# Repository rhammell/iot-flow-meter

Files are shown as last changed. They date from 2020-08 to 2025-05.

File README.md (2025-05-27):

# iot-flow-meter
This repository contains the project files used to build an IoT enabled flow meter. This project was submitted to Hackster.io as part of the [Cellular IoT Challenge](https://www.hackster.io/contests/soracomcontest#category-331), where it was selected as the grand prize winner. 

Read the [project page](https://www.hackster.io/rhammell/river-monitoring-with-an-iot-flow-meter-9af852) on Hackster.io for a complete project description and build tutorial. 

# Overview

<p align="center">
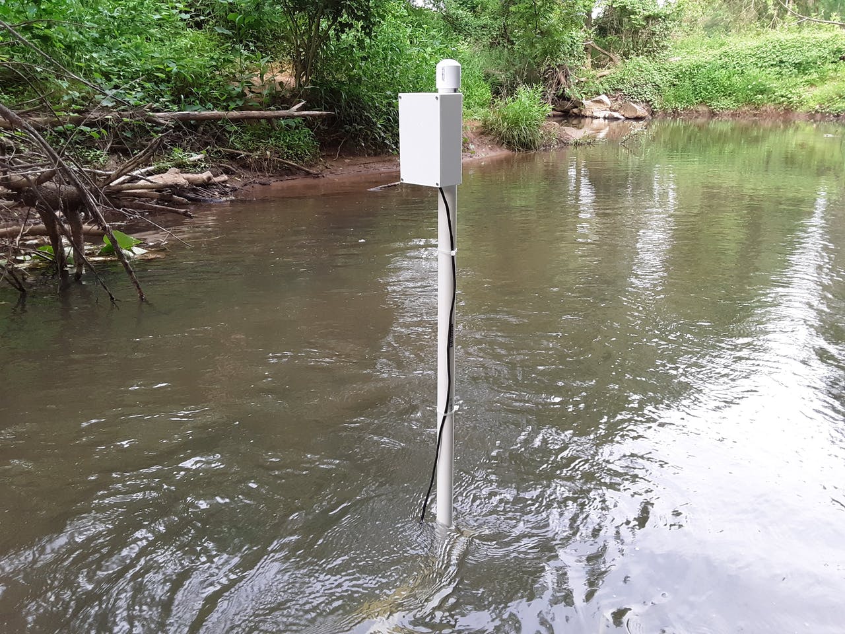
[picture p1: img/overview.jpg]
  
  <br>
  <span><i>IoT flow meter deployed to a local river</i></span>
</p>

This project demonstrates how to build an internet connected flow meter that continuously measures a river's flow rate and makes real-time data available to users online.

The system can be deployed to remote rivers with a one-time setup, and can be left to run on its own, automatically collecting data without the need for users to be present. Multiple meters can be placed throughout a river to collect many points of data.

Measurement data is pushed to the cloud through the system's cellular network connectivity, enabled by a Soracom Global SIM card, and can be viewed online through Soracom Harvest. AWS IoT and CloudWatch services are used to send email notifications to users when the river's flow rate reaches a critical level.

# Background

<p align="center">
  
</p>

The flow rate of a river measures the volume of water that passes through a specific point over time. This rate rises and falls as water from rainfall flows in and out of the river system.

Measuring a river's flow rate can yield valuable information for a variety purposes:

- Hydrology: Long term trends in flow rate give insights into the watershed system that feeds the river and how it changes over time.
- Ecology: Speed of river water determines if it can support different species of plants or animals.
- Flood Warning: Spikes in the flow rate can give early warning for incoming flooding and can be correlated to rainfall reports.
- Recreation Safety: Real-time measurements can warn canoers/kayakers if it is safe to travel along the river.

Currently, measuring the flow rate of remote river areas is a very hands-on process. Surveyors need to hike out to the river of interest carrying their measuring equipment, set it up, take a measurement, disassemble it, and hike back.

Because of the effort required to collect a measurement, it is only done periodically for certain rivers. Without continuous monitoring many of the insights that flow rate provides are lost.

This project aims to solve this problem by making flow rate data easier to collect and more readily available to users who need it.

# How it Works

<p align="center">
  <a target="_blank" href="https://www.youtube.com/watch?v=L7kpcUOq6Nk">
    
  </a>
  <br>
  <span><i>IoT Flow Meter Overview Video</i></span>
</p>

The IoT flow meter consists of a sensor and electronics, connected to a PVC pipe support structure, that can be deployed to a river to collect flow rate data.

A flow meter sensor is connected to the structure's vertical pipe at an adjustable height where it is held submerged underwater. The electronics are contained in an upper housing at the top of the structure outside of the water.

<p align="center">
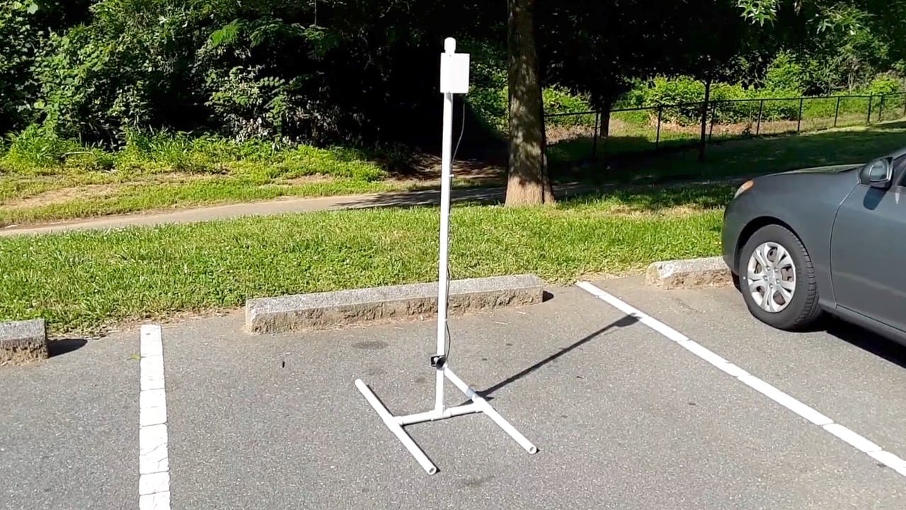
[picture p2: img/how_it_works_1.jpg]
  
  <br>
  <span><i>IoT flow meter structure and components</i></span>
</p>
<p align="center">
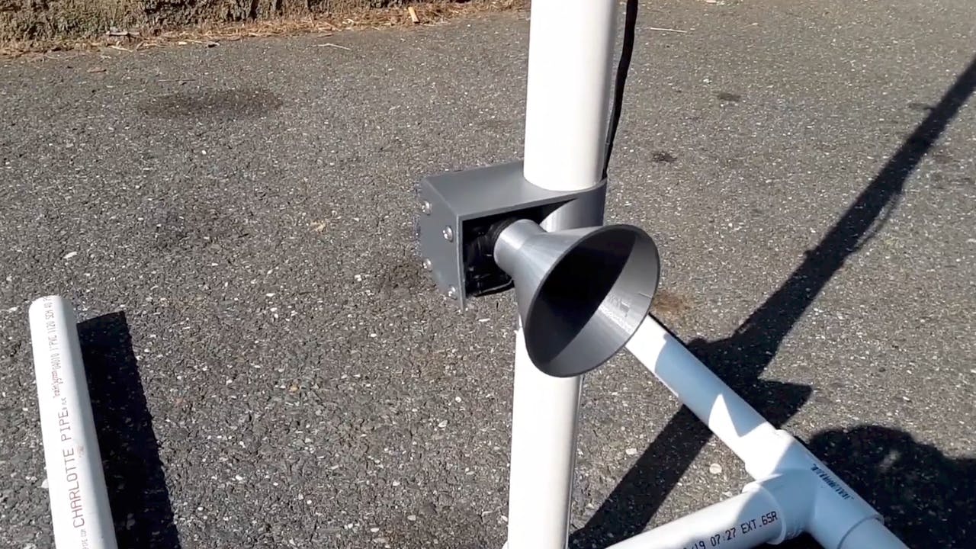
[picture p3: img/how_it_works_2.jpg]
  
  <br>
  <span><i>Flow meter sensor connected to structure</i></span>
</p>
<p align="center">
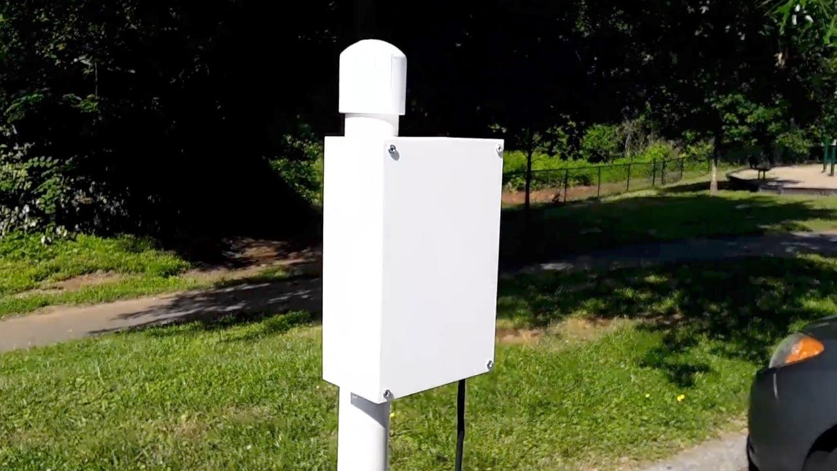
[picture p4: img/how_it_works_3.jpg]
  
  <br>
  <span><i>IoT flow meter deployed to a local river</i></span>
</p>

The system utilizes a YF-S201 liquid flow meter sensor, which contains a magnetic pinwheel that is spun by incoming water.

As more water enters the sensor the wheel spins faster, and this rate of spin (Hz) can be used to calculate how many liters of water flow through the sensor per minute (L/min), called the flow rate.

<p align="center">
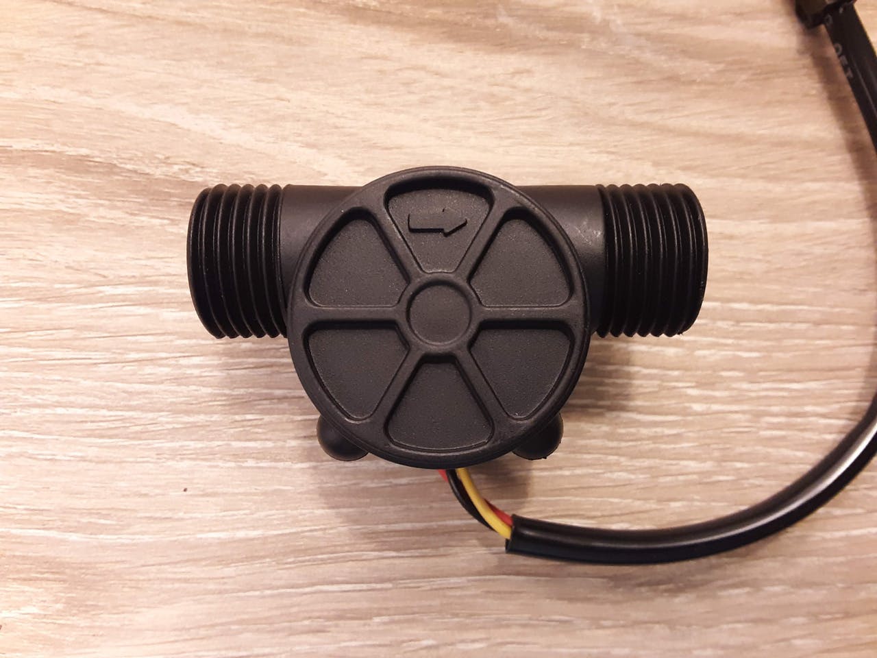
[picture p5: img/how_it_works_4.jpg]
  
  <br>
  <span><i>YF-S201 liquid flow meter sensor</i></span>
</p>
<p align="center">
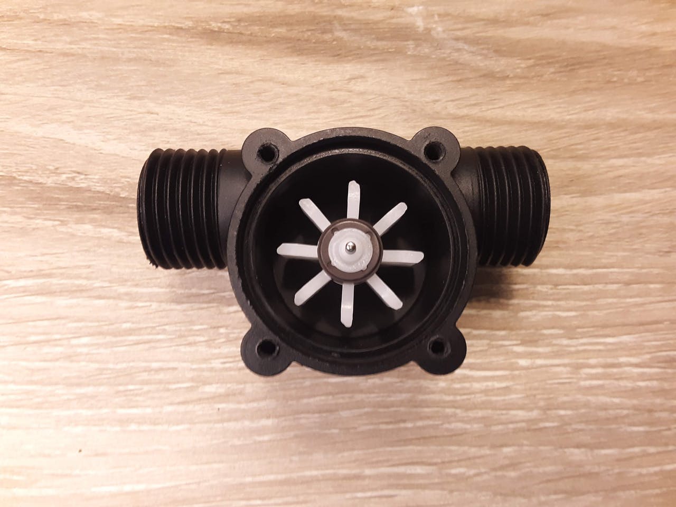
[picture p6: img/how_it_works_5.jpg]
  
  <br>
  <span><i>Magnetic pinwheel housed within the sensor</i></span>
</p>
<p align="center">
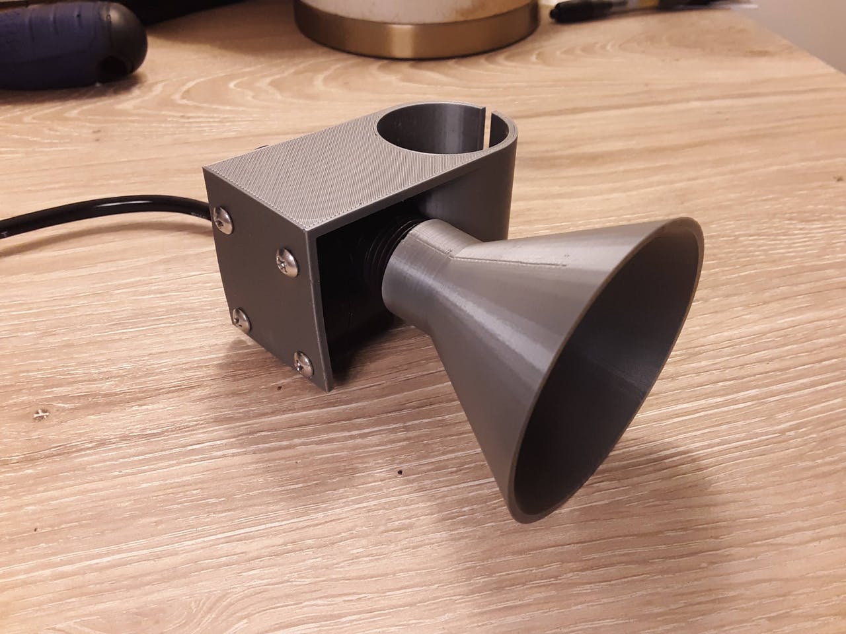
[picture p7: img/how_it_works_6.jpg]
  
  <br>
  <span><i>3D printed bracket and funnel attached to sensor</i></span>
</p>

Note: This flow rate only tells the liters of water passing through the sensor itself, not the entire river. The sensor's flow rate is strongly correlated to the river's actual flow rate, but is not measuring it directly. The IoT flow meter provides only the sensor's flow rate and uses this as an approximation for the entire river.

A 3D printed bracket is used to connect the sensor to the PVC pipe structure and a 3D printed funnel guides river water into the mouth of the sensor.

The electronics of the system include a Raspberry Pi, 3G USB modem with a Soracom Global SIM, and external battery, which are contained in a 3D printed housing. The sensor is connected to the Pi by water-sealed jumper wires that run the length of the vertical pipe into the housing.

<p align="center">
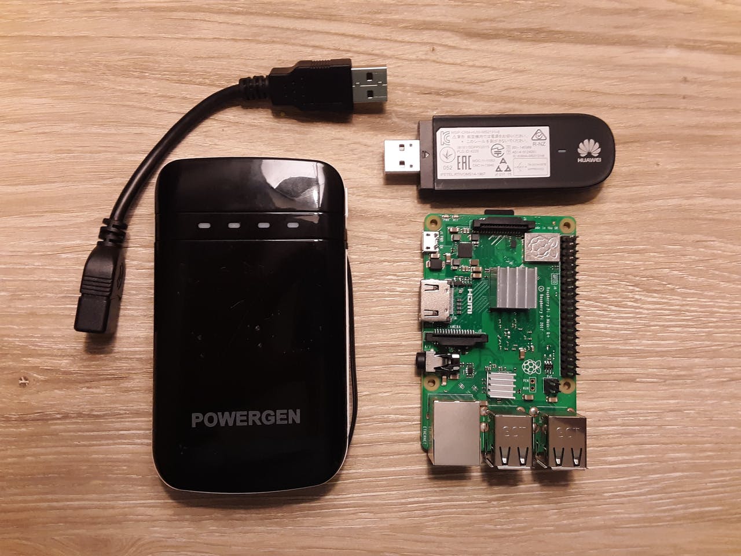
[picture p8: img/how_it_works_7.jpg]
  
  <br>
  <span><i>Raspberry Pi, 3G USB modem with Soracom Global SIM, and external battery</i></span>
</p>
<p align="center">
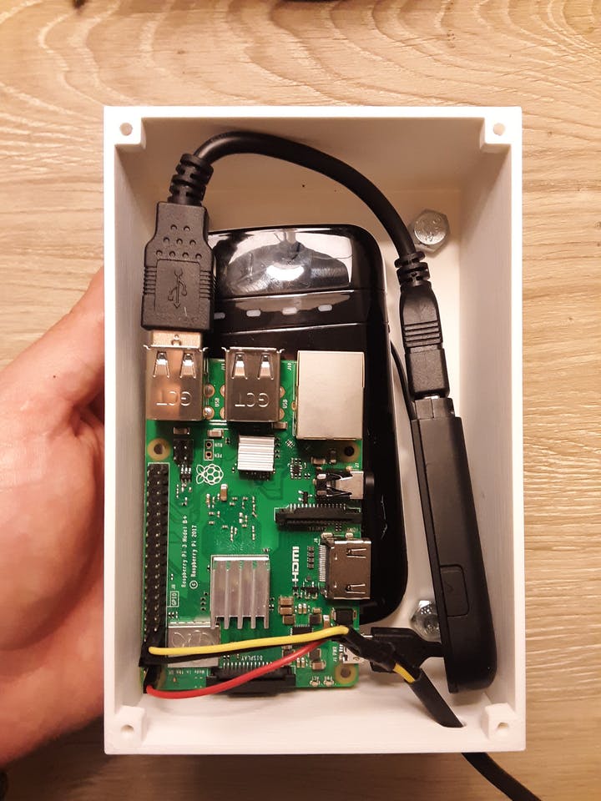
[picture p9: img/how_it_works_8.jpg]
  
  <br>
  <span><i>Electronics in 3D printed housing</i></span>
</p>

The Pi runs a Python script where ever minute a flow rate measurement is collected from the sensor and, using the cellular connectivity provided by the modem and SIM card, pushed to the cloud.

The script makes an HTTP POST request to Soracom's Unified Endpoint which forwards the data along to two services: Soracom Harvest and Soracom Funnel.

<p align="center">
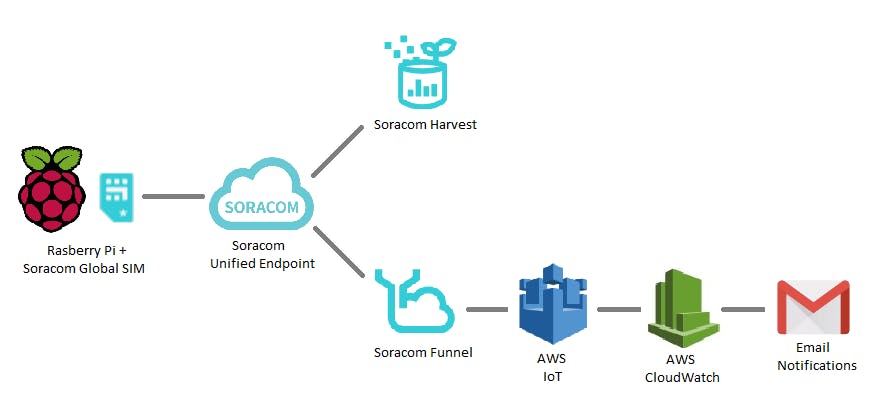
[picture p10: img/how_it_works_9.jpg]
  
  <br>
  <span><i>Overview of information flow</i></span>
</p>

Soracom Harvest allows for easy real-time visualization of the incoming data. The console displays a live graph showing updated data values as they stream in. Users can monitor how the data changes over a selected window of time.

<p align="center">
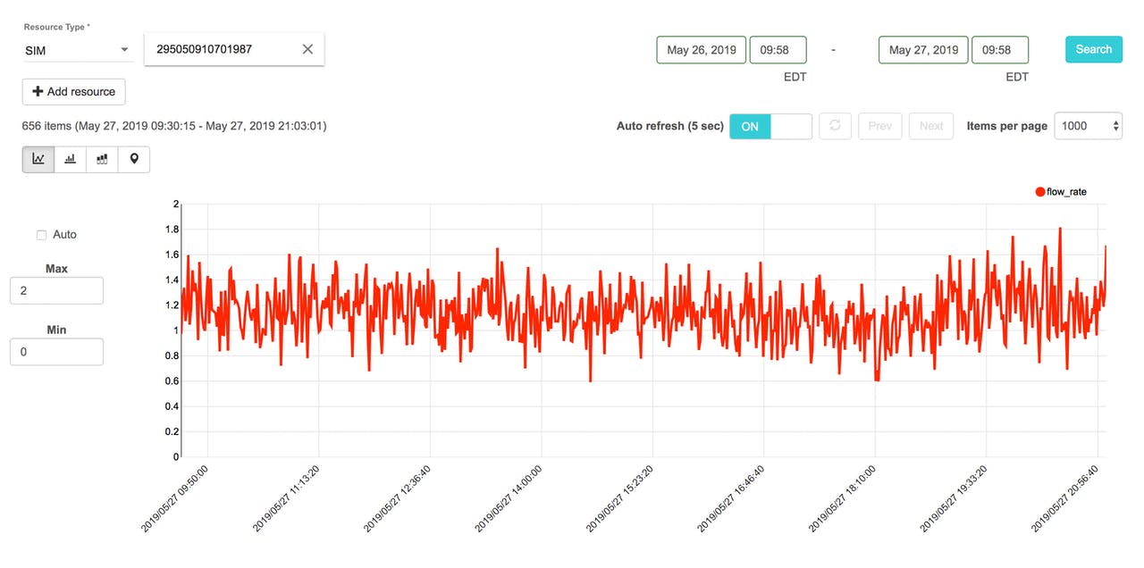
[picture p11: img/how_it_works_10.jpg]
  
  <br>
  <span><i>Soracom Harvest console</i></span>
</p>
<p align="center">
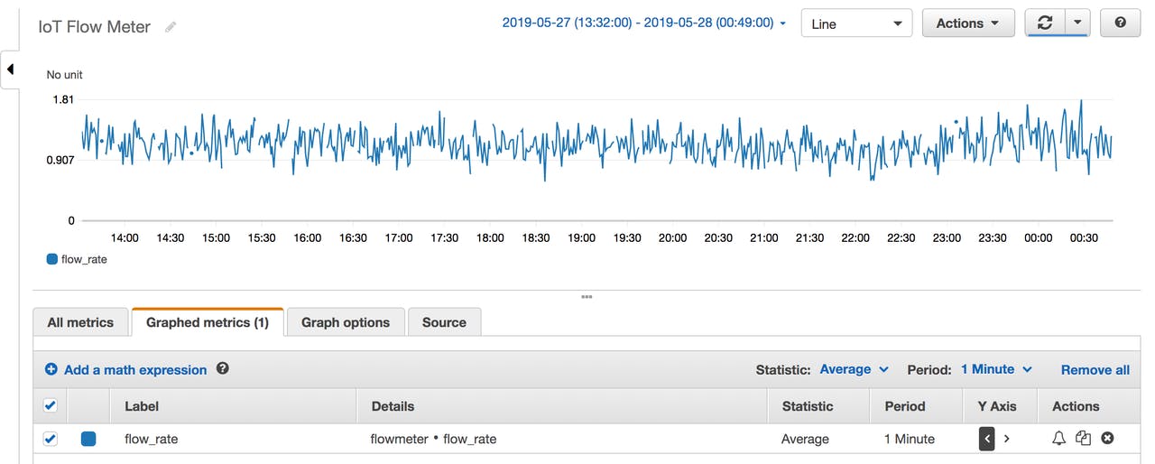
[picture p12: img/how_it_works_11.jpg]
  
  <br>
  <span><i>AWS Cloudwatch console</i></span>
</p>
<p align="center">
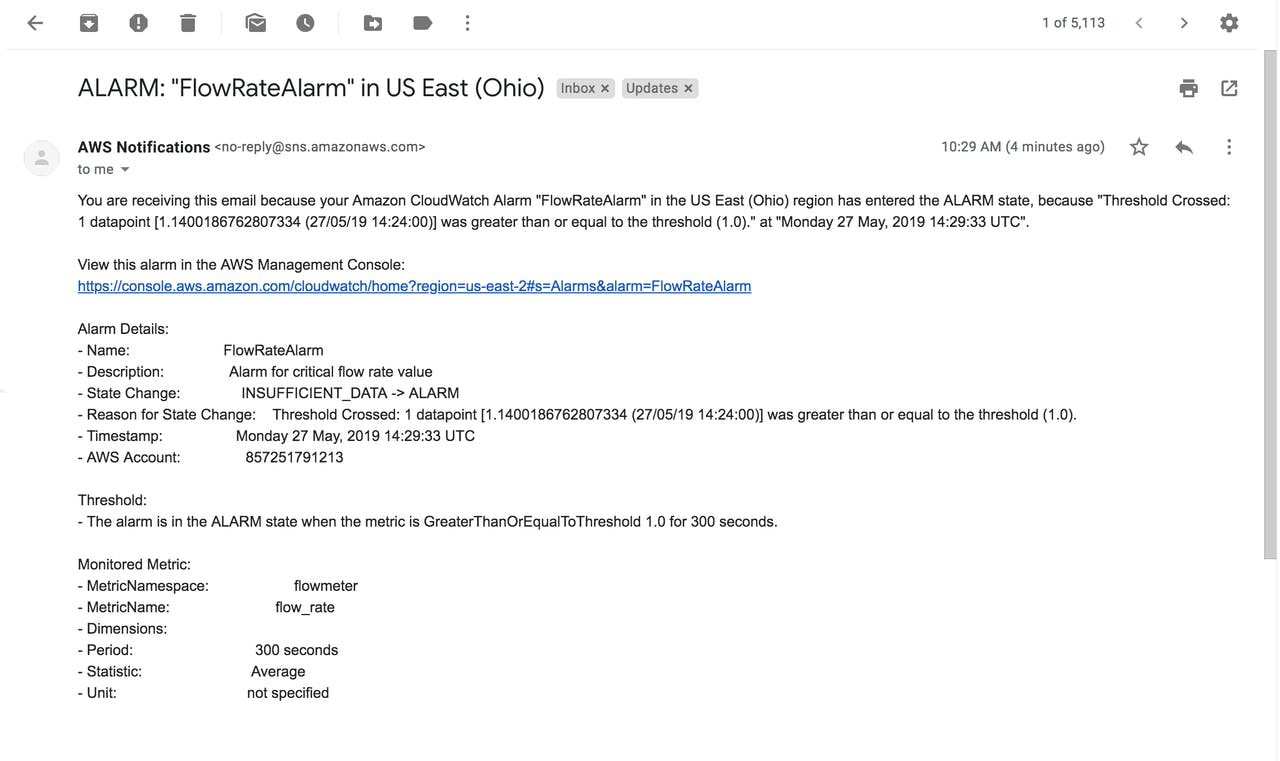
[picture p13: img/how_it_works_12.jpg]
  
  <br>
  <span><i>Email alarm notification</i></span>
</p>

Soracom Funnel takes the data and forwards it further on it by sending it to an AWS IoT endpoint, where an AWS IoT rule is then used to push the data to AWS CloudWatch.

A CloudWatch alarm is configured to monitor when the flow rate surpasses a critical value and automatically sends out an email notification to any subscribed users letting them know that the alarm has been triggered. This feature allows users to stay aware of important changes in the river's flow rate without having to monitor it live.

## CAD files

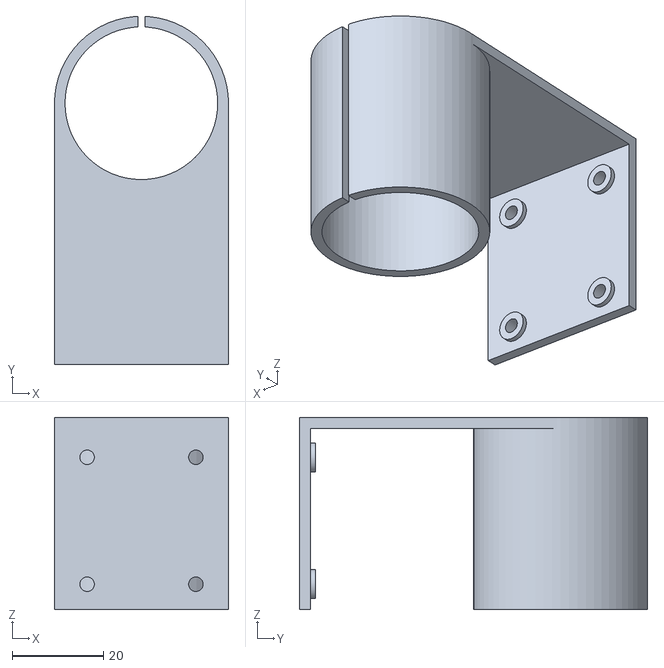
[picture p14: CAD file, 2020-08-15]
3d_models/flow_meter_bracket_oy0BGOlrMj.stl
38.1 x 76.2 x 42.1

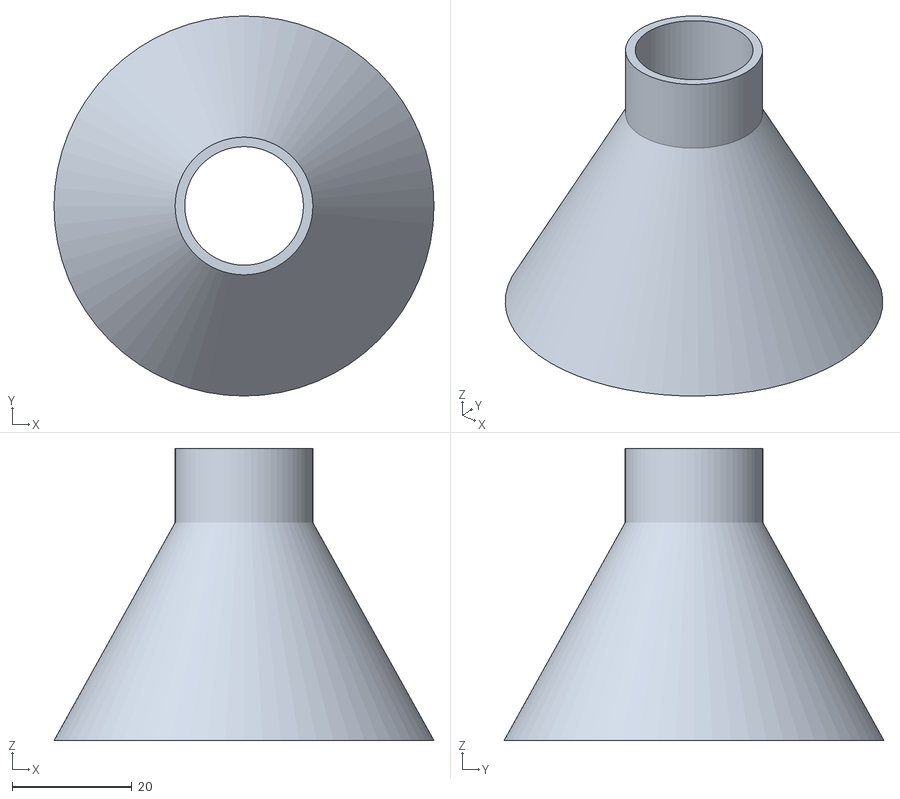
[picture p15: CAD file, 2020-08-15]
3d_models/flow_meter_funnel_b5NHmwqcIl.stl
63.5 x 63.5 x 48.8

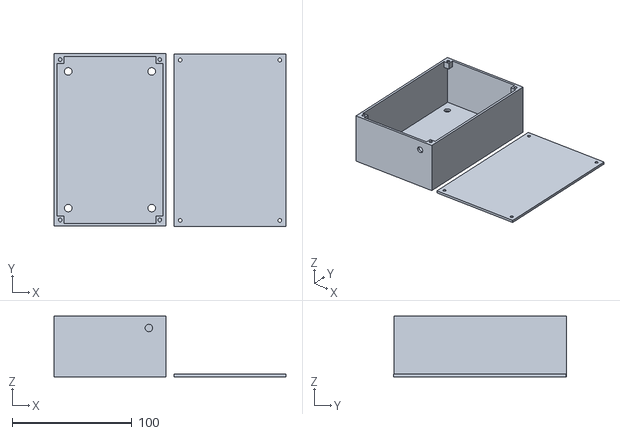
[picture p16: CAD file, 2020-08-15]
3d_models/electronics_housing_fJtRBpcLXU.stl
194.1 x 144.9 x 50.8

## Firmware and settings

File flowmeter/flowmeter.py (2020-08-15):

import json
import time
from datetime import datetime
import RPi.GPIO as GPIO
import requests
  
class FlowMeter():
    ''' Class representing the flow meter sensor which handles input pulses
        and calculates current flow rate (L/min) measurement
    '''
    
    def __init__(self):
        self.flow_rate = 0.0
        self.last_time = datetime.now()
  
    def pulseCallback(self, p):
        ''' Callback that is executed with each pulse 
            received from the sensor 
        '''
       
        # Calculate the time difference since last pulse recieved
        current_time = datetime.now()
        diff = (current_time - self.last_time).total_seconds()
       
        # Calculate current flow rate
        hertz = 1. / diff
        self.flow_rate = hertz / 7.5
       
        # Reset time of last pulse
        self.last_time = current_time
    
    def getFlowRate(self):
        ''' Return the current flow rate measurement. 
            If a pulse has not been received in more than one second, 
            assume that flow has stopped and set flow rate to 0.0
        '''
       
        if (datetime.now() - self.last_time).total_seconds() > 1:
            self.flow_rate = 0.0
        
        return self.flow_rate
  
def main():
    ''' Main function for repeatedly collecting flow rate measurements
        and sending them to the SORACOM API
    '''
   
    # Configure GPIO pins
    INPUT_PIN = 7
    GPIO.setmode(GPIO.BOARD)
    GPIO.setup(INPUT_PIN, GPIO.IN, pull_up_down=GPIO.PUD_UP)
   
    # Init FlowMeter instance and pulse callback
    flow_meter = FlowMeter()
    GPIO.add_event_detect(INPUT_PIN,
                          GPIO.RISING,
                          callback=flow_meter.pulseCallback,
                          bouncetime=20)
   
    # Begin infinite loop
    while True:
  
        # Get current timestamp and flow meter reading
        timestamp = str(datetime.now())
        flow_rate = flow_meter.getFlowRate()
        print('Timestamp: %s' % timestamp)
        print('Flow rate: %f' % flow_rate)

        # Build payload
        payload = {
            'timestamp': timestamp,
            'flow_rate': flow_rate
        }
          
        # Publish to Soracom API
        headers = {'Content-Type': 'application/json'}
        try:
            print('Publishing to SORACOM API...')
            r = requests.post('http://unified.soracom.io',
                               data=json.dumps(payload),
                               headers=headers,
                               timeout=5)
        except:
            print('Error: Connection timeout.')
       
        # Delay
        time.sleep(5)
  
if __name__ == '__main__':
   main()
